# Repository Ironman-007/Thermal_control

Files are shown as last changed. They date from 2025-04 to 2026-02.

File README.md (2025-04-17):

# Thermal_control

Due to my research, I always need to measure, log, and control the temperature of the environment during some experiment, such as TVAC test, etc. So I think it would be great to have a standard Kit to do this.
I made this for my personal usage, with 4 channels of RTD to measure temeprature and 4 channels of heater control.

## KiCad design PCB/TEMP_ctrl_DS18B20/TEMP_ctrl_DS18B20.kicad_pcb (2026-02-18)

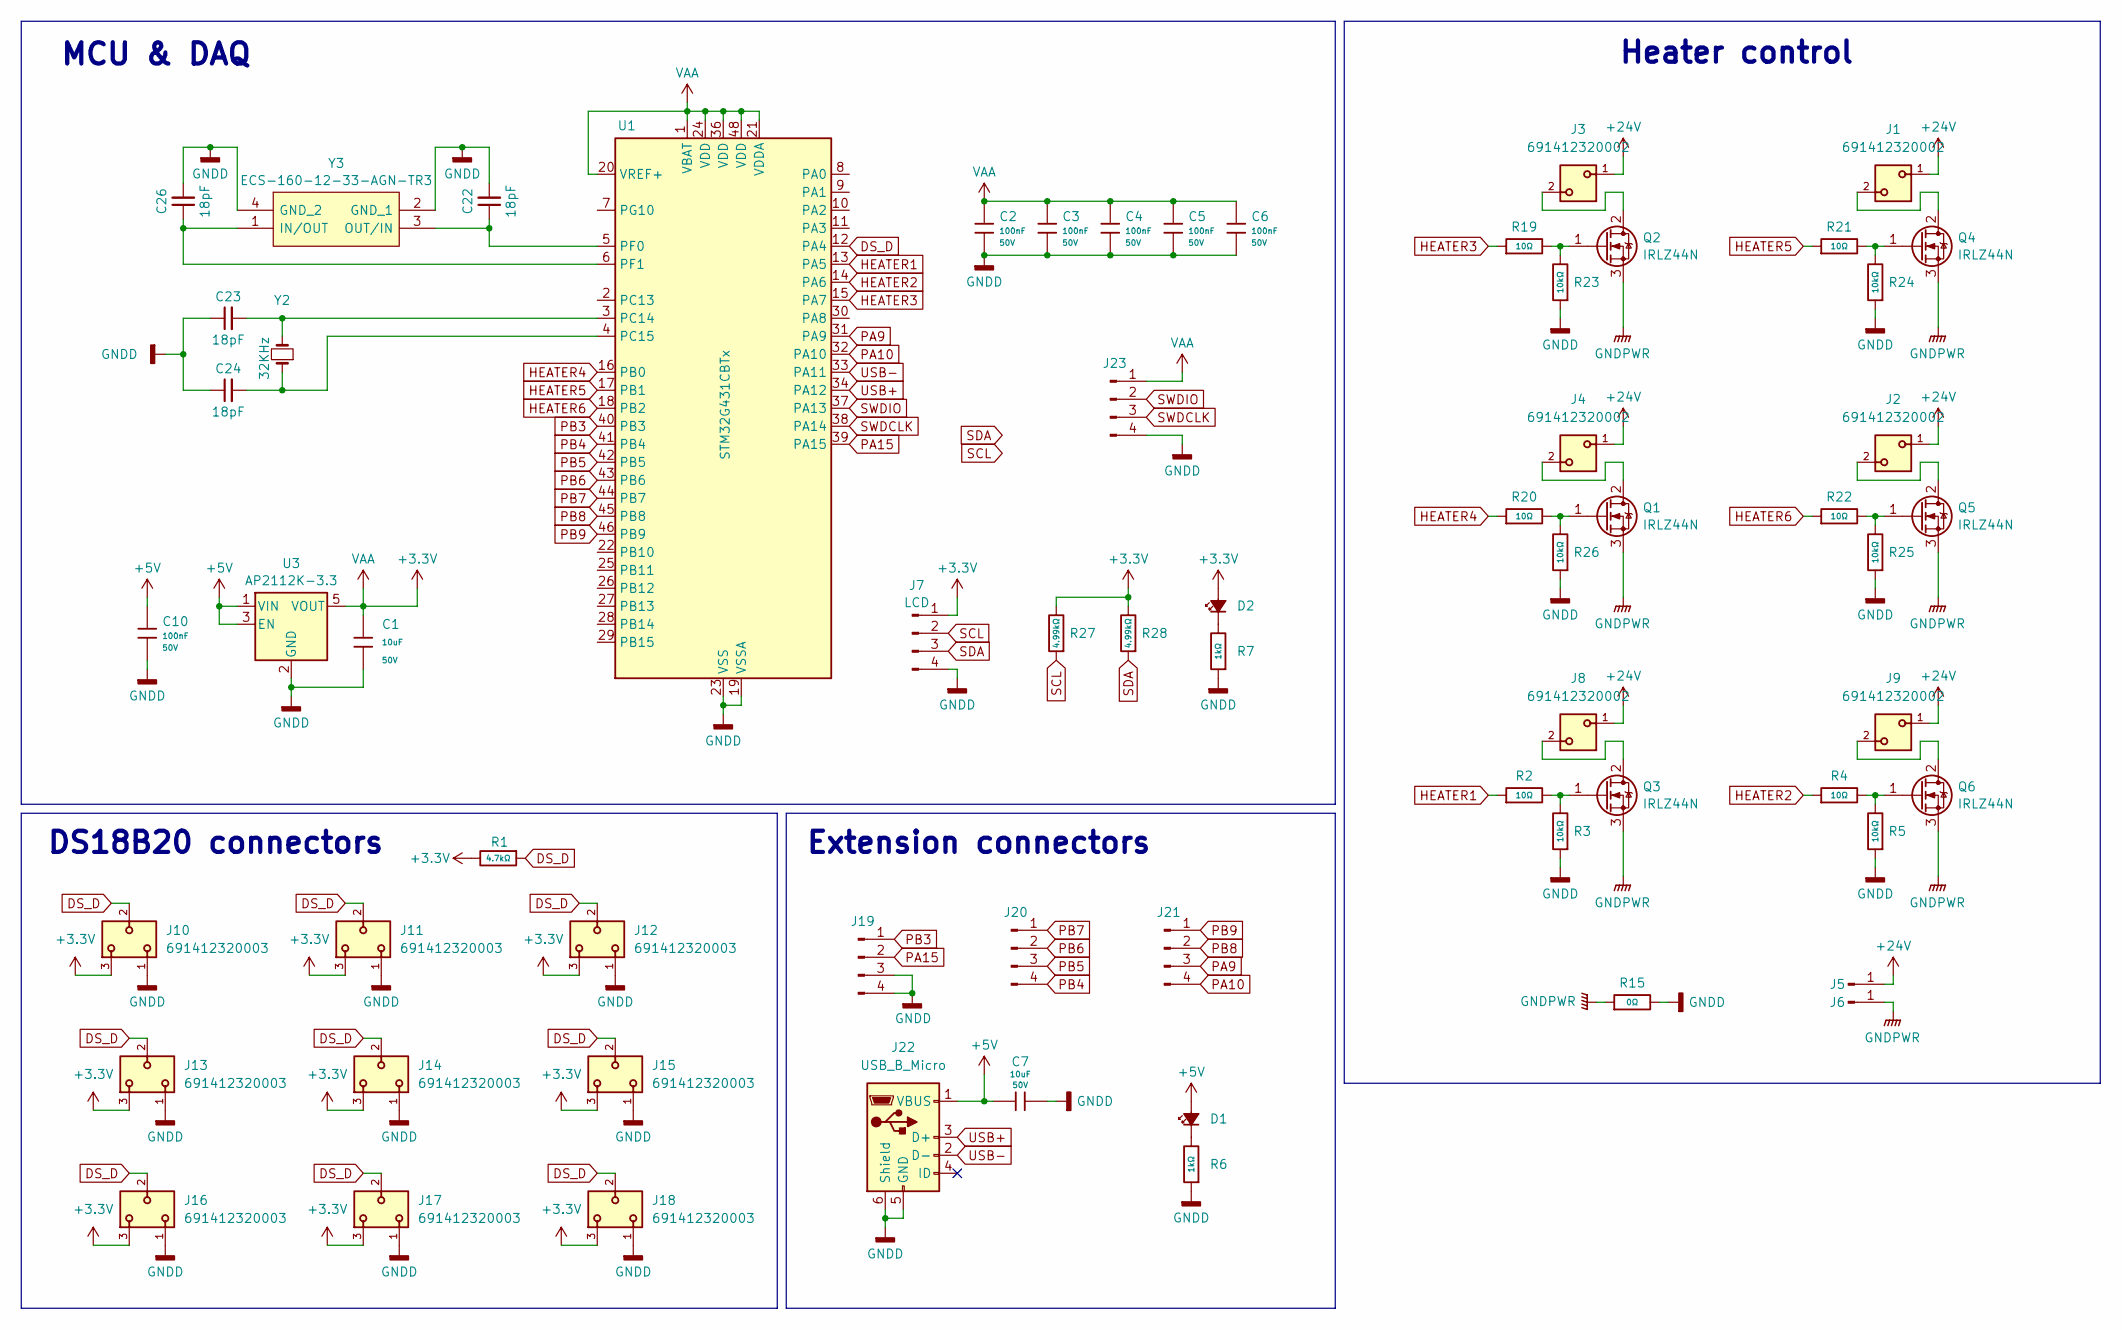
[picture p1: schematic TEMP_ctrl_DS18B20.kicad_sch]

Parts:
C1, C7: 10uF; C_1206; Voltage Rated 50V; Tolerance ±10%; Part CL31B104KBCNNNC; LCSC C24497
C2, C3, C4, C5, C6, C10: 100nF; C_0603_1608Metric; Voltage Rated 50V; Tolerance ±10%; Part CL31B104KBCNNNC; LCSC C24497
C22, C23, C24, C26: 18pF; C_0402_1005Metric_Pad0.74x0.62mm_HandSolder
D1, D2: LED_Small_Filled; LED_1206_3216Metric
J1, J2, J3, J4, J8, J9: 691412320002
J5, J6: Conn_01x01_Pin; TestPoint_Pad_4.0x4.0mm
J7: LCD; PinHeader_1x04_P2.54mm_Vertical
J10, J11, J12, J13, J14, J15, J16, J17, J18: 691412320003
J19, J20, J21, J23: Conn_01x04_Pin; PinHeader_1x04_P2.54mm_Vertical
J22: USB_B_Micro; USB_Micro-B_Amphenol_10104110_Horizontal
Q1, Q2, Q3, Q4, Q5, Q6: IRLZ44N; TO-220-3_Vertical
R1: 4.7kΩ; R_1206; Overload Voltage (Max) 200V; Tolerance ±1%; Part 1206W4F1001T5E; LCSC C4410
R2, R4, R19, R20, R21, R22: 10Ω; R_1206; Overload Voltage (Max) 200V; Tolerance ±1%; Part 1206W4F1001T5E; LCSC C4410
R3, R5, R23, R24, R25, R26: 10kΩ; R_1206; Overload Voltage (Max) 200V; Tolerance ±1%; Part 1206W4F1001T5E; LCSC C4410
R6, R7: 1kΩ; R_1206; Overload Voltage (Max) 200V; Tolerance ±1%; Part 1206W4F1001T5E; LCSC C4410
R15: 0Ω; R_1206; Overload Voltage (Max) 200V; Tolerance ±1%; Part 1206W4F0000T5E; LCSC C17888
R27, R28: 4.99kΩ; R_1206; Overload Voltage (Max) 200V; Tolerance ±1%; Part 1206W4F1001T5E; LCSC C4410
U1: STM32G431CBTx; LQFP-48_7x7mm_P0.5mm
U3: AP2112K-3.3; SOT-23-5
Y2: 32KHz; Crystal_SMD_3215-2Pin_3.2x1.5mm
Y3: ECS-160-12-33-AGN-TR3; XTAL_ECS-160-12-33-AGN-TR3; Manufacturer_Part_Number ECS-160-12-33-AGN-TR3; Mouser Part Number 520-160-12-33AGN-TR3

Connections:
+3.3V: C1.1, C2.1, C3.1, C4.1, C5.1, C6.1, D2.2 (A), J7.1, J10.3, J11.3, J12.3, J13.3, J14.3, J15.3, J16.3, J17.3, J18.3, J23.1, R1.2, R27.2, R28.2, U1.1 (VBAT), U1.20 (VREF+), U1.21 (VDDA), U1.24 (VDD), U1.36 (VDD), U1.48 (VDD), U3.5 (VOUT)
+5V: C7.1, C10.1, D1.2 (A), J22.1 (VBUS), U3.1 (VIN), U3.3 (EN)
+24V: J1.1, J2.1, J3.1, J4.1, J5.1, J8.1, J9.1
DS_D: J10.2, J11.2, J12.2, J13.2, J14.2, J15.2, J16.2, J17.2, J18.2, R1.1, U1.12 (PA4)
GNDD: C1.2, C2.2, C3.2, C4.2, C5.2, C6.2, C7.2, C10.2, C22.2, C23.1, C24.1, C26.2, J7.4, J10.1, J11.1, J12.1, J13.1, J14.1, J15.1, J16.1, J17.1, J18.1, J19.3, J19.4, J22.5 (GND), J22.6 (Shield), J23.4, R3.1, R5.1, R6.1, R7.1, R15.2, R23.1, R24.1, R25.1, R26.1, U1.19 (VSSA), U1.23 (VSS), U1.35 (VSS), U1.47 (VSS), U3.2 (GND), Y3.2 (GND_1), Y3.4 (GND_2)
GNDPWR: J6.1, Q1.3 (S), Q2.3 (S), Q3.3 (S), Q4.3 (S), Q5.3 (S), Q6.3 (S), R15.1
HEATER1: R2.1, U1.13 (PA5)
HEATER2: R4.1, U1.14 (PA6)
HEATER3: R19.1, U1.15 (PA7)
HEATER4: R20.1, U1.16 (PB0)
HEATER5: R21.1, U1.17 (PB1)
HEATER6: R22.1, U1.18 (PB2)
unnamed: D1.1 (K), R6.2
unnamed: D2.1 (K), R7.2
unnamed: J4.2, Q1.2 (D)
unnamed: Q1.1 (G), R20.2, R26.2
unnamed: J3.2, Q2.2 (D)
unnamed: Q2.1 (G), R19.2, R23.2
unnamed: J8.2, Q3.2 (D)
unnamed: Q3.1 (G), R2.2, R3.2
unnamed: J1.2, Q4.2 (D)
unnamed: Q4.1 (G), R21.2, R24.2
unnamed: J2.2, Q5.2 (D)
unnamed: Q5.1 (G), R22.2, R25.2
unnamed: J9.2, Q6.2 (D)
unnamed: Q6.1 (G), R4.2, R5.2
unnamed: C23.2, U1.3 (PC14), Y2.2
unnamed: C24.2, U1.4 (PC15), Y2.1
unnamed: C22.1, U1.5 (PF0), Y3.3 (OUT/IN)
unnamed: C26.1, U1.6 (PF1), Y3.1 (IN/OUT)
PA9: J21.3, U1.31 (PA9)
PA10: J21.4, U1.32 (PA10)
PA15: J19.2, U1.39 (PA15)
PB3: J19.1, U1.40 (PB3)
PB4: J20.4, U1.41 (PB4)
PB5: J20.3, U1.42 (PB5)
PB6: J20.2, U1.43 (PB6)
PB7: J20.1, U1.44 (PB7)
PB8: J21.2, U1.45 (PB8)
PB9: J21.1, U1.46 (PB9)
SCL: J7.2, R27.1
SDA: J7.3, R28.1
SWDCLK: J23.3, U1.38 (PA14)
SWDIO: J23.2, U1.37 (PA13)
USB+: J22.3 (D+), U1.34 (PA12)
USB-: J22.2 (D-), U1.33 (PA11)

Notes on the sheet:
Heater control
DS18B20 connectors
Extension connectors
MCU & DAQ

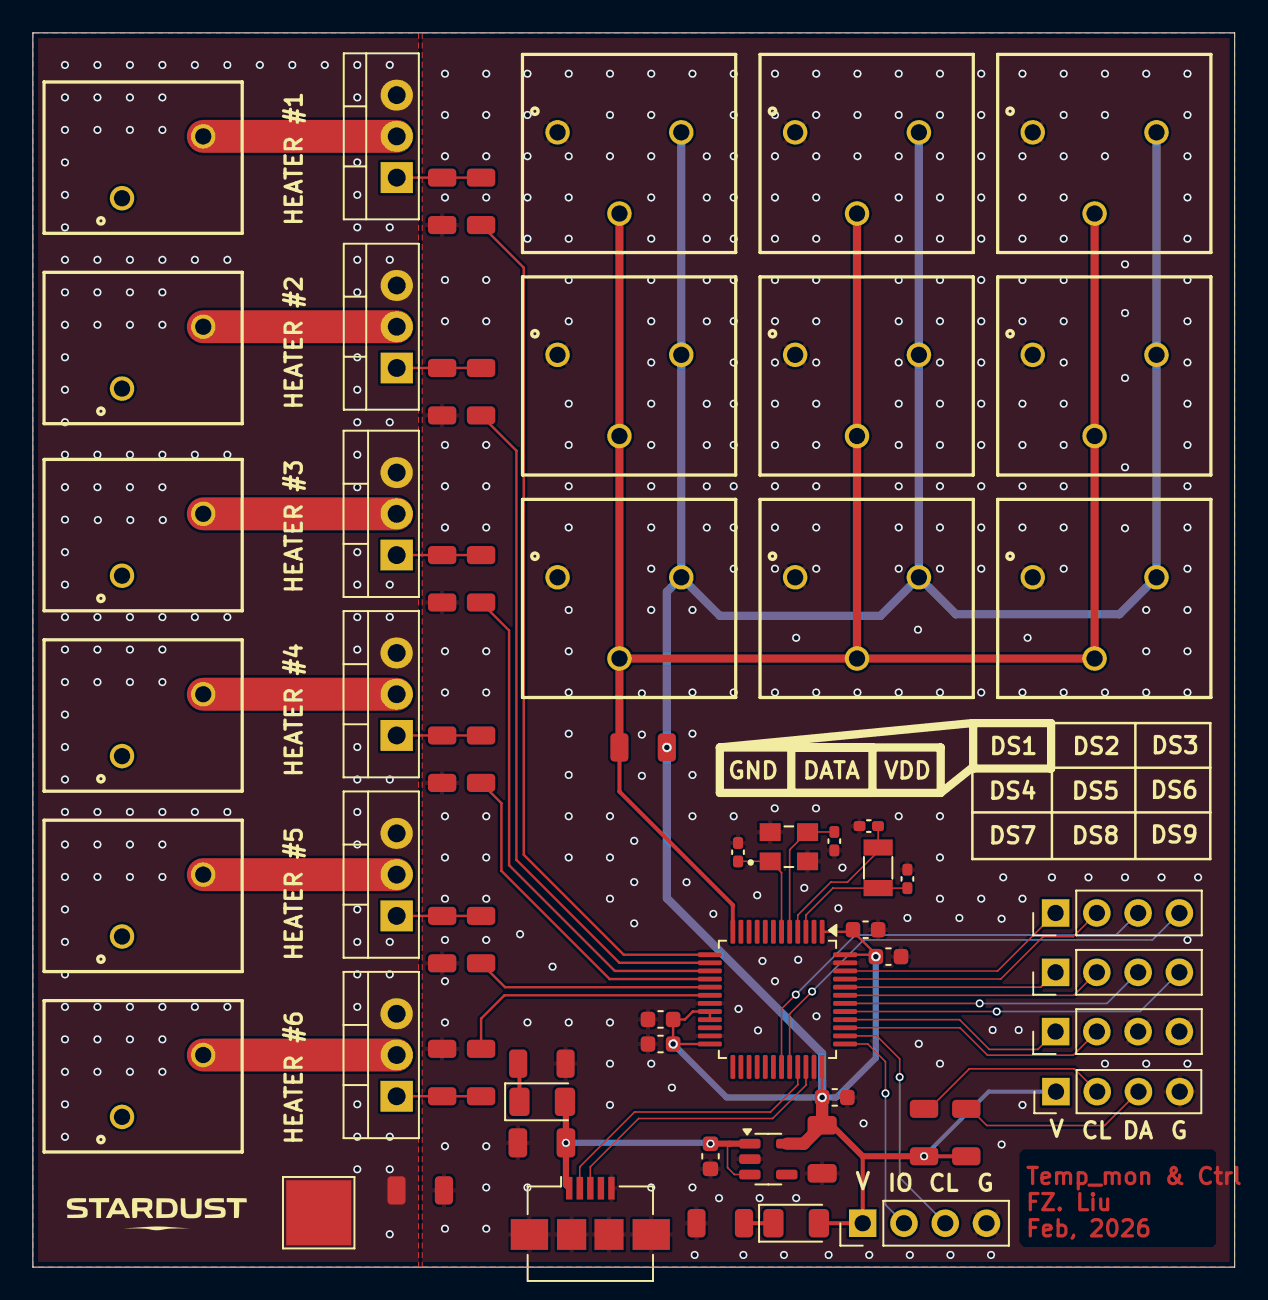
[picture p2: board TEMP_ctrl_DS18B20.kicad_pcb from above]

Board: 2 copper layers, 74.0 x 76.0 mm, 65 parts (1 on the bottom side), 46 nets.

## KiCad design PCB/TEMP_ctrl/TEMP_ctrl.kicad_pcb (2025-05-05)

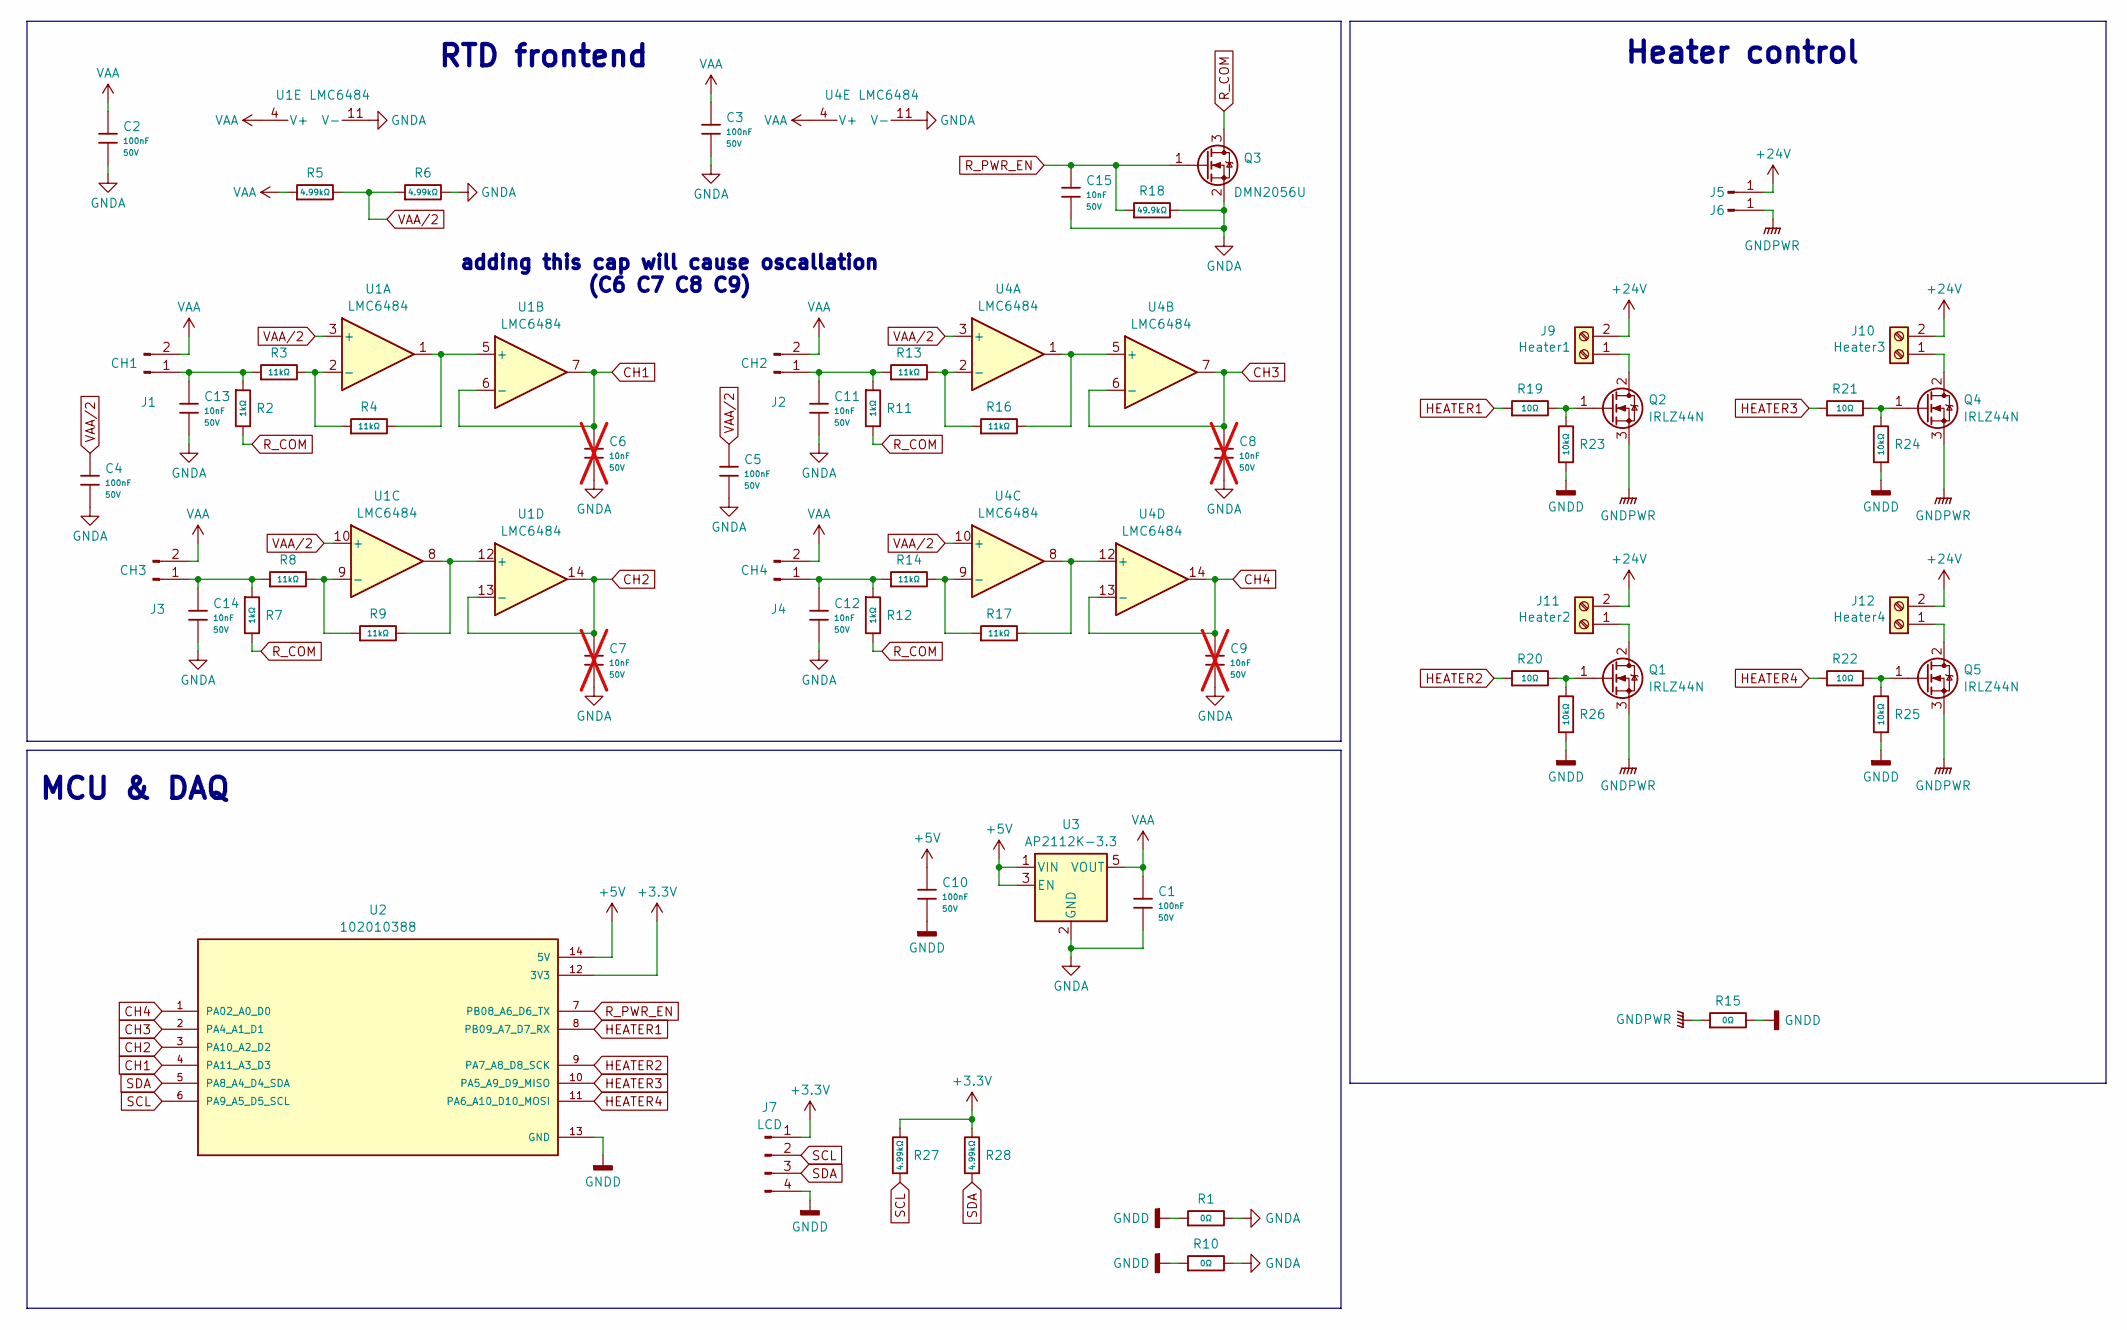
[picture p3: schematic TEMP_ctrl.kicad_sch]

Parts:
C1, C2, C3, C4, C5, C10: 100nF; C_1206; Voltage Rated 50V; Tolerance ±10%; Part CL31B104KBCNNNC; LCSC C24497
C6, C7, C8, C9: 10nF; C_1206; Voltage Rated 50V; Tolerance ±10%; Part CL31B104KBCNNNC; LCSC C24497; not fitted
C11, C12, C13, C14, C15: 10nF; C_1206; Voltage Rated 50V; Tolerance ±10%; Part CL31B104KBCNNNC; LCSC C24497
J1: CH1; TerminalBlock_Xinya_XY308-2.54-2P_1x02_P2.54mm_Horizontal
J2: CH2; TerminalBlock_Xinya_XY308-2.54-2P_1x02_P2.54mm_Horizontal
J3: CH3; TerminalBlock_Xinya_XY308-2.54-2P_1x02_P2.54mm_Horizontal
J4: CH4; TerminalBlock_Xinya_XY308-2.54-2P_1x02_P2.54mm_Horizontal
J5, J6: Conn_01x01_Pin; TestPoint_Pad_4.0x4.0mm
J7: LCD; PinHeader_1x04_P2.54mm_Vertical
J9: Heater1; TerminalBlock_MaiXu_MX126-5.0-02P_1x02_P5.00mm
J10: Heater3; TerminalBlock_MaiXu_MX126-5.0-02P_1x02_P5.00mm
J11: Heater2; TerminalBlock_MaiXu_MX126-5.0-02P_1x02_P5.00mm
J12: Heater4; TerminalBlock_MaiXu_MX126-5.0-02P_1x02_P5.00mm
Q1, Q2, Q4, Q5: IRLZ44N; TO-220-3_Vertical
Q3: DMN2056U; SOT-23
R1, R10, R15: 0Ω; R_1206; Overload Voltage (Max) 200V; Tolerance ±1%; Part 1206W4F0000T5E; LCSC C17888
R2, R7, R11, R12: 1kΩ; R_1206; Overload Voltage (Max) 200V; Tolerance ±1%; Part 1206W4F1001T5E; LCSC C4410
R3, R4, R8, R9, R13, R14, R16, R17: 11kΩ; R_1206; Overload Voltage (Max) 200V; Tolerance ±1%; Part 1206W4F1001T5E; LCSC C4410
R5, R6, R27, R28: 4.99kΩ; R_1206; Overload Voltage (Max) 200V; Tolerance ±1%; Part 1206W4F1001T5E; LCSC C4410
R18: 49.9kΩ; R_1206; Overload Voltage (Max) 200V; Tolerance ±1%; Part 1206W4F1001T5E; LCSC C4410
R19, R20, R21, R22: 10Ω; R_1206; Overload Voltage (Max) 200V; Tolerance ±1%; Part 1206W4F1001T5E; LCSC C4410
R23, R24, R25, R26: 10kΩ; R_1206; Overload Voltage (Max) 200V; Tolerance ±1%; Part 1206W4F1001T5E; LCSC C4410
U1, U4: LMC6484; SOIC-14_L8.7-W3.9-P1.27-LS6.0-BL
U2: 102010388; MODULE_102010388; PARTREV N/A
U3: AP2112K-3.3; SOT-23-5

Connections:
+3.3V: J7.1, R27.2, R28.2, U2.12 (3V3)
+5V: C10.1, U2.14 (5V), U3.1 (VIN), U3.3 (EN)
+24V: J5.1, J9.2, J10.2, J11.2, J12.2
CH1: C6.1, U1.6 (-), U1.7, U2.4 (PA11_A3_D3)
CH2: C7.1, U1.13 (-), U1.14, U2.3 (PA10_A2_D2)
CH3: C8.1, U2.2 (PA4_A1_D1), U4.6 (-), U4.7
CH4: C9.1, U2.1 (PA02_A0_D0), U4.13 (-), U4.14
GNDA: C1.2, C2.2, C3.2, C4.2, C5.2, C6.2, C7.2, C8.2, C9.2, C11.2, C12.2, C13.2, C14.2, C15.2, Q3.2 (S), R1.2, R6.2, R10.2, R18.2, U1.11 (V-), U3.2 (GND), U4.11 (V-)
GNDD: C10.2, J7.4, R1.1, R10.1, R15.2, R23.1, R24.1, R25.1, R26.1, U2.13 (GND)
GNDPWR: J6.1, Q1.3 (S), Q2.3 (S), Q4.3 (S), Q5.3 (S), R15.1
HEATER1: R19.1, U2.8 (PB09_A7_D7_RX)
HEATER2: R20.1, U2.9 (PA7_A8_D8_SCK)
HEATER3: R21.1, U2.10 (PA5_A9_D9_MISO)
HEATER4: R22.1, U2.11 (PA6_A10_D10_MOSI)
unnamed: C13.1, J1.1, R2.1, R3.1
unnamed: C11.1, J2.1, R11.1, R13.1
unnamed: C14.1, J3.1, R7.1, R8.1
unnamed: C12.1, J4.1, R12.1, R14.1
unnamed: J9.1, Q2.2 (D)
unnamed: J10.1, Q4.2 (D)
unnamed: J11.1, Q1.2 (D)
unnamed: J12.1, Q5.2 (D)
unnamed: Q1.1 (G), R20.2, R26.2
unnamed: Q2.1 (G), R19.2, R23.2
unnamed: Q4.1 (G), R21.2, R24.2
unnamed: Q5.1 (G), R22.2, R25.2
unnamed: R3.2, R4.1, U1.2 (-)
unnamed: R4.2, U1.1, U1.5 (+)
unnamed: R8.2, R9.1, U1.9 (-)
unnamed: R9.2, U1.8, U1.12 (+)
unnamed: R13.2, R16.1, U4.2 (-)
unnamed: R16.2, U4.1, U4.5 (+)
unnamed: R14.2, R17.1, U4.9 (-)
unnamed: R17.2, U4.8, U4.12 (+)
R_COM: Q3.3 (D), R2.2, R7.2, R11.2, R12.2
R_PWR_EN: C15.1, Q3.1 (G), R18.1, U2.7 (PB08_A6_D6_TX)
SCL: J7.2, R27.1, U2.6 (PA9_A5_D5_SCL)
SDA: J7.3, R28.1, U2.5 (PA8_A4_D4_SDA)
VAA: C1.1, C2.1, C3.1, J1.2, J2.2, J3.2, J4.2, R5.1, U1.4 (V+), U3.5 (VOUT), U4.4 (V+)
VAA/2: C4.1, C5.1, R5.2, R6.1, U1.3 (+), U1.10 (+), U4.3 (+), U4.10 (+)

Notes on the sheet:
Heater control
RTD frontend
adding this cap will cause oscallation (C6 C7 C8 C9)
MCU & DAQ

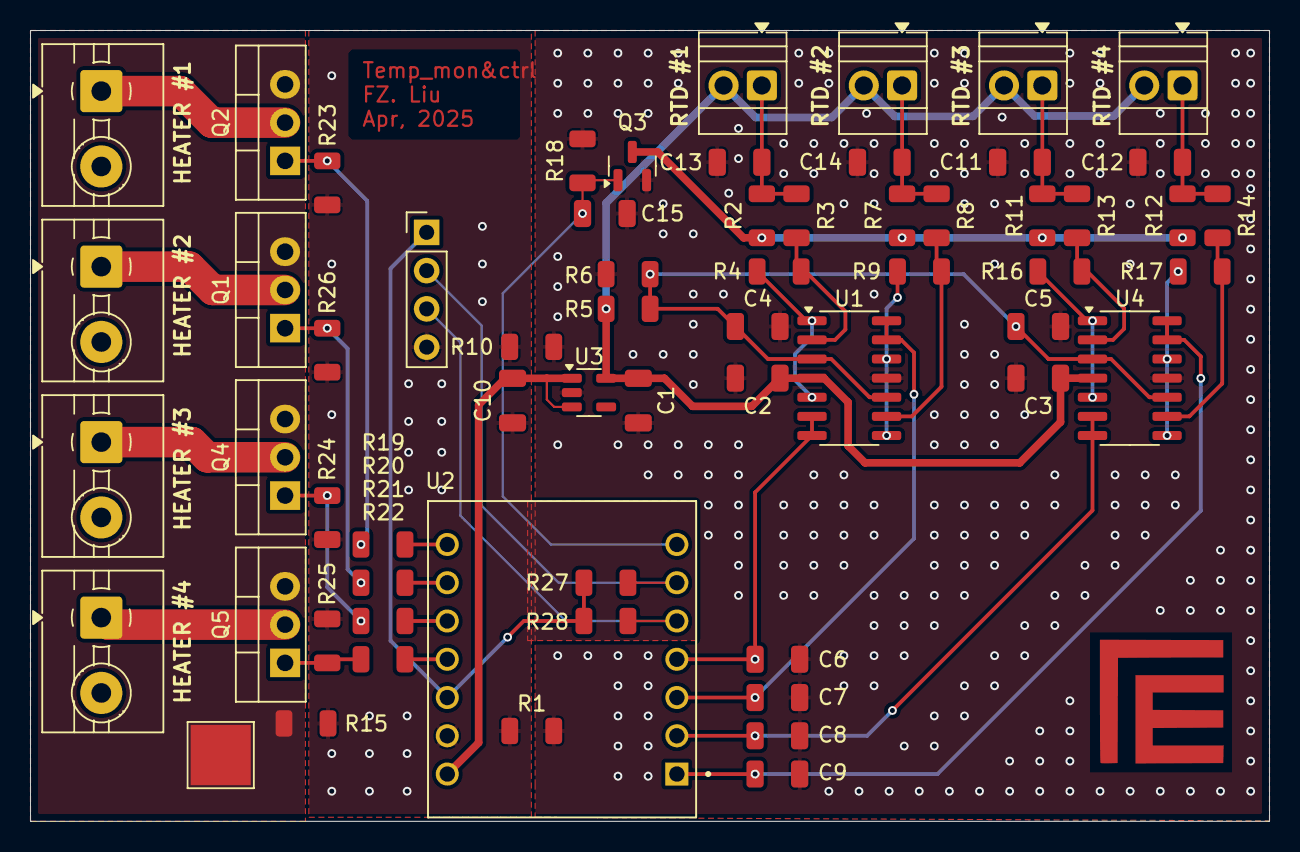
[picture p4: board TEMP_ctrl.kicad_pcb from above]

Board: 2 copper layers, 82.2 x 52.5 mm, 63 parts (1 on the bottom side), 40 nets.

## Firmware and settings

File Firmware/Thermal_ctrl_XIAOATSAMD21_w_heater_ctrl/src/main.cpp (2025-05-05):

#include "system.h"
#include "Sample_data.h"
#include "heater.h"
#include "Comm.h"

void setup() {
  system_init();
  heater_init();
  RTD_init();
}

void loop() {
  Update_sampling();
  SendData2GUI();
  Getdata_fromGUI();
  heater_set_pwm(heater_pwm_1, heater_pwm_2, heater_pwm_3, heater_pwm_4);
  delay(Sampling_period);
}

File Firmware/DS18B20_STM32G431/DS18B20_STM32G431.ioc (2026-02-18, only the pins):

Mcu.UserName=STM32G431CBTx
PA0.Signal=ADC1_IN1
PA1.Signal=ADC1_IN2
PA11.Signal=USB_DM
PA12.Signal=USB_DP
PA13.Signal=SYS_JTMS-SWDIO
PA14.Signal=SYS_JTCK-SWCLK
PA2.Signal=ADC1_IN3
PA3.Signal=ADC1_IN4
PA4.Signal=ADC2_IN17
PA5.Signal=ADC2_IN13
PA6.Signal=ADC2_IN3
PA7.Signal=ADC2_IN4
PB11.Signal=ADC2_IN14
PB15.Signal=ADC2_IN15
PB2.Signal=ADC2_IN12
PC14-OSC32_IN.Signal=RCC_OSC32_IN
PC15-OSC32_OUT.Signal=RCC_OSC32_OUT
PF0-OSC_IN.Signal=RCC_OSC_IN
PF1-OSC_OUT.Signal=RCC_OSC_OUT

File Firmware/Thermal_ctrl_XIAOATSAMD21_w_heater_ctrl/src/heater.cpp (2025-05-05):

#include "heater.h"

void heater_init(void) {
  pinMode(HEATER_PIN_1, OUTPUT);
  pinMode(HEATER_PIN_2, OUTPUT);
  pinMode(HEATER_PIN_3, OUTPUT);
  pinMode(HEATER_PIN_4, OUTPUT);

  digitalWrite(HEATER_PIN_1, LOW);
  digitalWrite(HEATER_PIN_2, LOW);
  digitalWrite(HEATER_PIN_3, LOW);
  digitalWrite(HEATER_PIN_4, LOW);
}

void heater_set_pwm(uint8_t heater_pwm_1, uint8_t heater_pwm_2, uint8_t heater_pwm_3, uint8_t heater_pwm_4) {
  analogWrite(HEATER_PIN_1, heater_pwm_1);
  analogWrite(HEATER_PIN_2, heater_pwm_2);
  analogWrite(HEATER_PIN_3, heater_pwm_3);
  analogWrite(HEATER_PIN_4, heater_pwm_4);
}

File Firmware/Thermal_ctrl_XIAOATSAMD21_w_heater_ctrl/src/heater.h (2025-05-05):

#pragma once

#include <Arduino.h>
#include "system.h"

#define HEATER_PIN_1 7
#define HEATER_PIN_2 8
#define HEATER_PIN_3 9
#define HEATER_PIN_4 10

extern void heater_init(void);
extern void heater_set_pwm(uint8_t heater_pwm_1, uint8_t heater_pwm_2, uint8_t heater_pwm_3, uint8_t heater_pwm_4);

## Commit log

2025-04-17 mac: working on the PCB
    [TEMP_ctrl.kicad_pcb, TEMP_ctrl.kicad_sch]
2025-04-18 pc: working on the PCB
    [TEMP_ctrl.kicad_pcb, TEMP_ctrl.kicad_sch]
2025-04-18 mac: finished PCB design
    [TEMP_ctrl.kicad_pcb, TEMP_ctrl.kicad_sch]
2025-05-04 mac: fisnihed RTDs calibration
    [TEMP_ctrl.kicad_pcb, TEMP_ctrl.kicad_sch]
2025-05-05 mac: PID calculation part working, then I need to send the data to the hardware.
    [TEMP_ctrl.kicad_pcb, TEMP_ctrl.kicad_sch]
2025-05-05 mac: PID control working.
2025-05-07 mac: create GUI for both thermal control boards
2025-06-05 mac: gui working, using this version
    [temperature_monitor_strip.kicad_pcb, temperature_monitor_strip.kicad_sch]
2026-02-16 PC: working on the DS18B20 PCB design
    [TEMP_ctrl_DS18B20.kicad_pcb, TEMP_ctrl_DS18B20.kicad_sch]
2026-02-18 PC: finished DS18B20 PCB design
    [TEMP_ctrl_DS18B20.kicad_pcb, TEMP_ctrl_DS18B20.kicad_sch]
